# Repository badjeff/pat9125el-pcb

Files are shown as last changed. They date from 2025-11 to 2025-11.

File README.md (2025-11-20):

# PAT9125EL PCB

[PixArt PAT9125EL-TKIT / TKMT](https://www.pixart.com/products-detail/72/PAT9125EL-TKIT___TKMT) low power optical tracking sensor breakout board.

- Be operated with 3.3V voltage level ONLY.
- Outlined as narrow as possible for side mount horizontally and perpendicular on low profile keyboards.

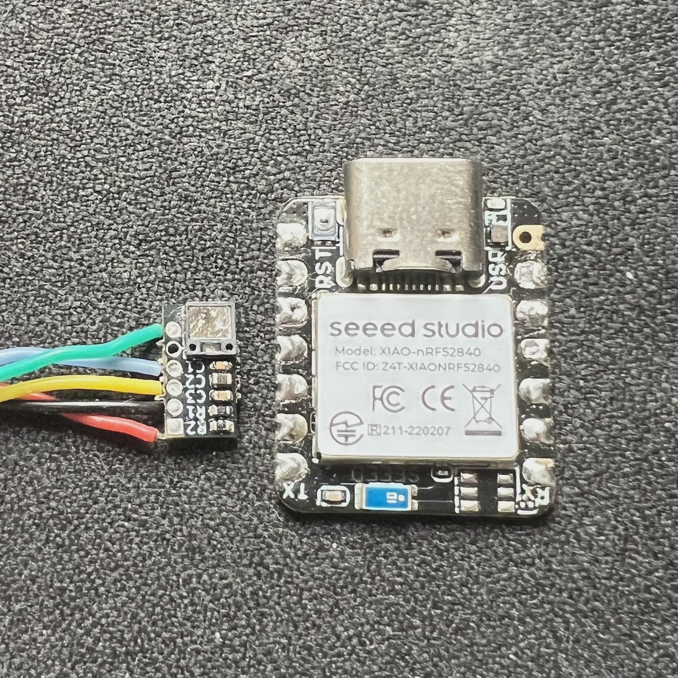
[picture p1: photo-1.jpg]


*Figure 1: Size comparing to Seeed XIAO BLE*

## PCB

Online preview avaliable [here](https://kicanvas.org/?github=https%3A%2F%2Fgithub.com%2Fbadjeff%2Fpat9125el-pcb), powered by [KiCanvas](https://github.com/theacodes/kicanvas).

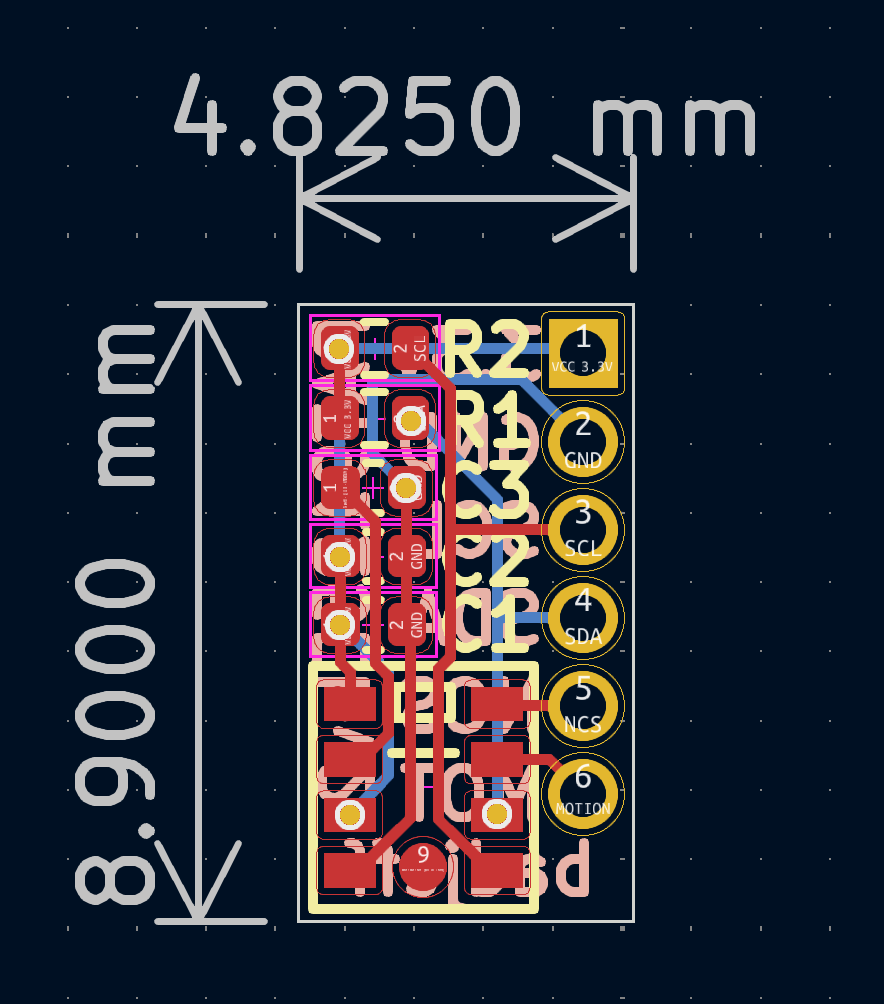
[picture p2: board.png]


*Figure 2: PCB edgecuts dimension*

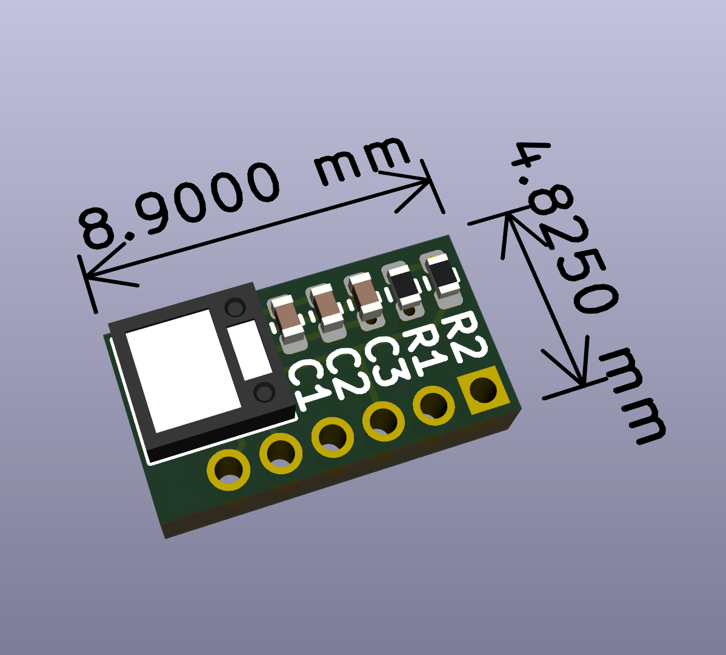
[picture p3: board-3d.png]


*Figure 3: PCB 3D View - 1.6mm FR4*

### BOM

|Designator|Footprint|Quantity|Value|LCSC Part #|
|-|-|-|-|-|
|C1|SMD 0402|1|100nF||
|C2|SMD 0402|1|10uF||
|C3|SMD 0402|1|4.7uF||
|R1, R2|SMD 0402|1|5K||
|U1|PAT9125EL|1|PAT9125EL-TKIT / TKMT||
|J1|1.27mm Pin header|1|1x6||

- SMD 0402 (Imperial) aka 1005 Metric.

### Board Characteristics

- Copper layer count: 2
- Board thickness: 1.6 mm or 1.2 mm or 1.0 mm
- Board overall dimensions: 4.825 x 8.9 mm

### Voltage level config

- 3.3V logic
- VIN: 3.3V

## License

Available under the [CERN-OHL-P v2](/LICENSE) permissive license.

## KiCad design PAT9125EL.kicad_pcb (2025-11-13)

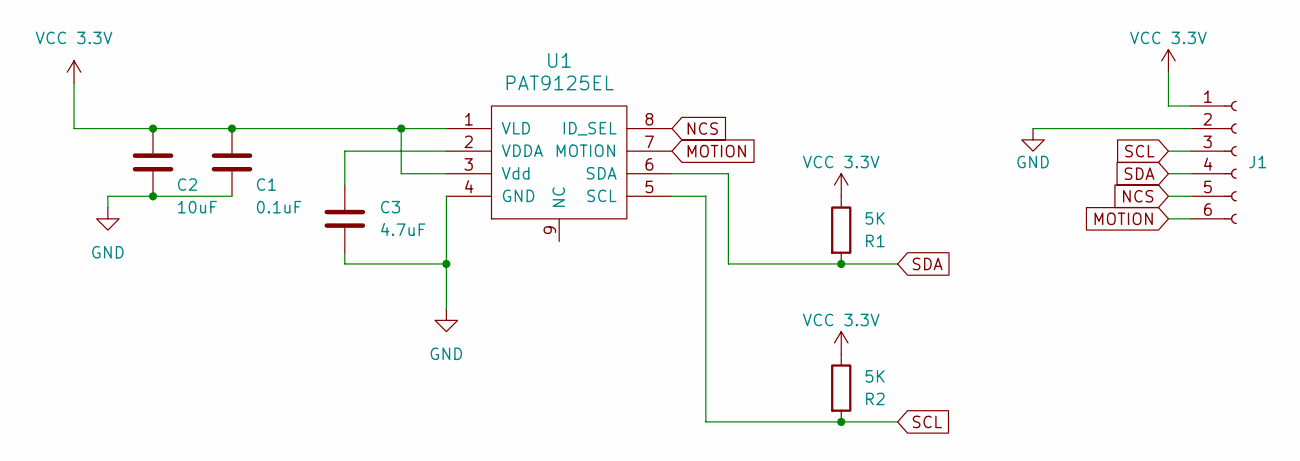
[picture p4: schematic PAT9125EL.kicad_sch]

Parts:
C1: 0.1uF; C_0402_1005Metric
C2: 10uF; C_0402_1005Metric
C3: 4.7uF; C_0402_1005Metric
J1: Conn_01x06_Socket; PinHeader_1x06_P1.27mm_Vertical
R1, R2: 5K; R_0402_1005Metric
U1: PAT9125EL

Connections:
GND: C1.2, C2.2, C3.2, J1.2, U1.4 (GND)
MOTION: J1.6, U1.7 (MOTION)
NCS: J1.5, U1.8 (ID_SEL)
unnamed: C3.1, U1.2 (VDDA)
SCL: J1.3, R2.2, U1.5 (SCL)
SDA: J1.4, R1.2, U1.6 (SDA)
VCC 3.3V: C1.1, C2.1, J1.1, R1.1, R2.1, U1.1 (VLD), U1.3 (Vdd)

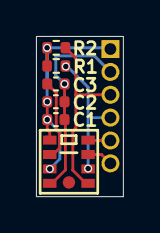
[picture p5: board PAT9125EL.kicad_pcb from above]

Board: 2 copper layers, 4.8 x 8.9 mm, 7 parts (0 on the bottom side), 7 nets.

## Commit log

2025-11-01 init commit
    [PAT9125EL.kicad_pcb, PAT9125EL.kicad_sch]
2025-11-13 shorten 1.5mm
    [PAT9125EL.kicad_pcb, PAT9125EL.kicad_sch]
2025-11-15 add panelized pcb
    [PAT9125EL_panelized.kicad_pcb]
